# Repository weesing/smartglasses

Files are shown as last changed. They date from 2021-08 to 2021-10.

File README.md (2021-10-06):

# Overview
- This is a smart glasses prototyping project to use a MCU (Arduino/ESP32) or Raspberry Pi (SBC).
- **All resources here are WIP.**

# Folders
| Folder | Description
| -- | --
| STLs | Contains the STL files for 3D printing the parts of the smart glasses prototype.
| src | Contains source code for Arduino IDE based programming (suitable for Arduinos and ESP32) and Raspberry Pi.
| design | The design files used for producing the STLs. The current software used for design is Microsoft 3D Builder.

# Basic design
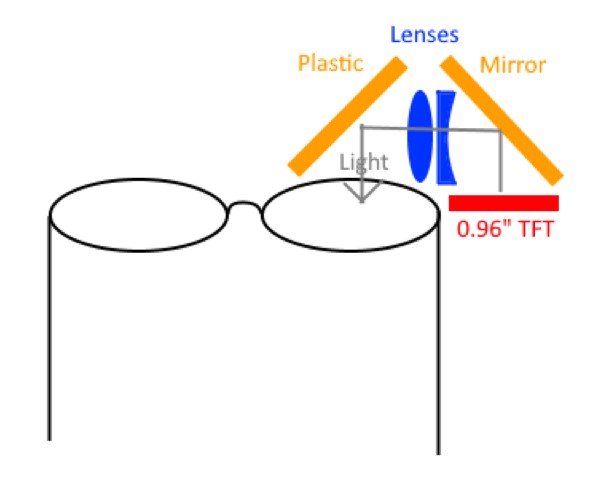
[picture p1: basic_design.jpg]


# Showcase
## Initial prototype with Arduino BLE Nano
<ul>
<li>Design with Arduino BLE Nano MCU and 0.49" OLED (monochrome) screen.
  <div class="row">
    <div class="col-md-12">
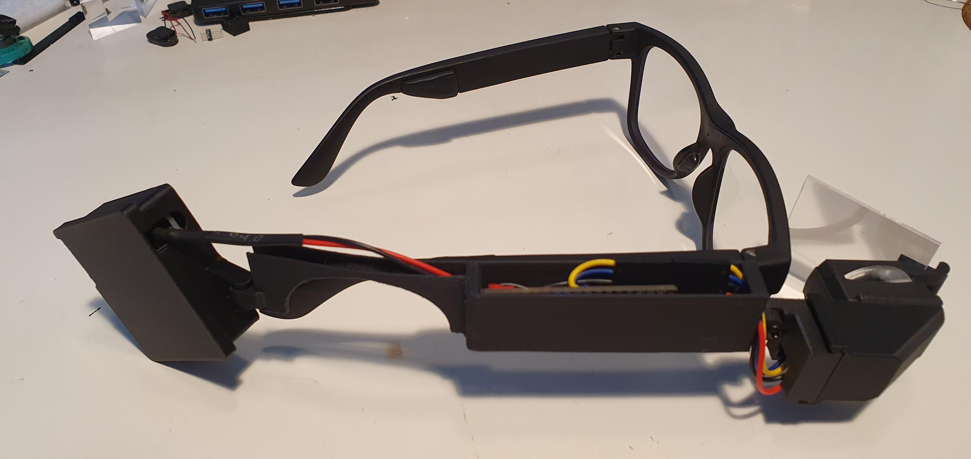
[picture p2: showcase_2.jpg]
    
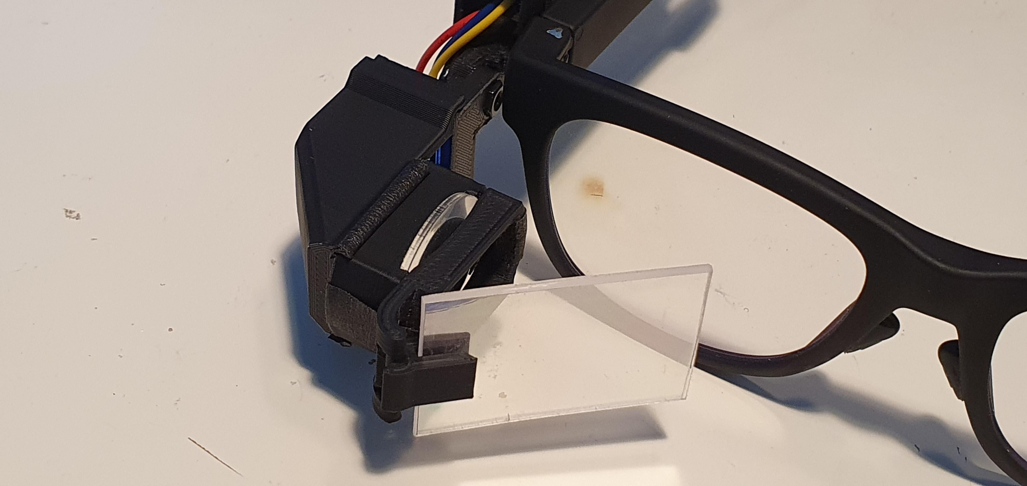
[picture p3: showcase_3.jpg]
    
    </div>
  </div>
</li>
<li>Code can be found in the sub-folder <code>src/arduino_ide</code></li>
</ul>

## Raspberry Pi Zero W console on the 0.96" TFT SPI display.
<ul>
<li>Displaying framebuffer of Raspbian Terminal on the display.</li>
  <div class="row">
    <div class="col-md-12">
    
    </div>
    <div class="col-md-12">
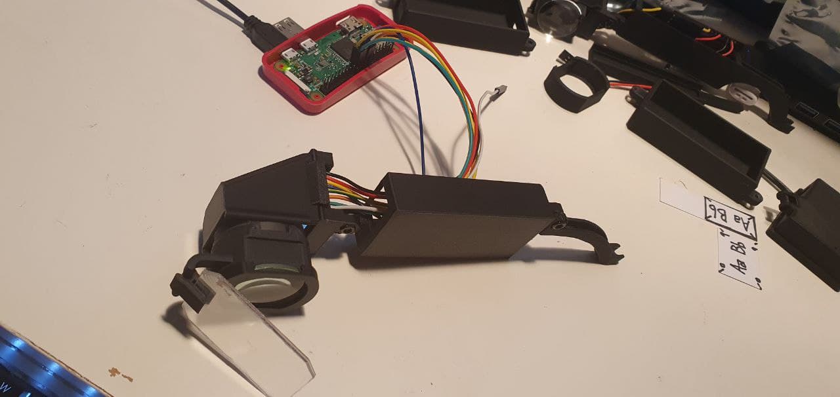
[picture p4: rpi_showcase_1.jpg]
    
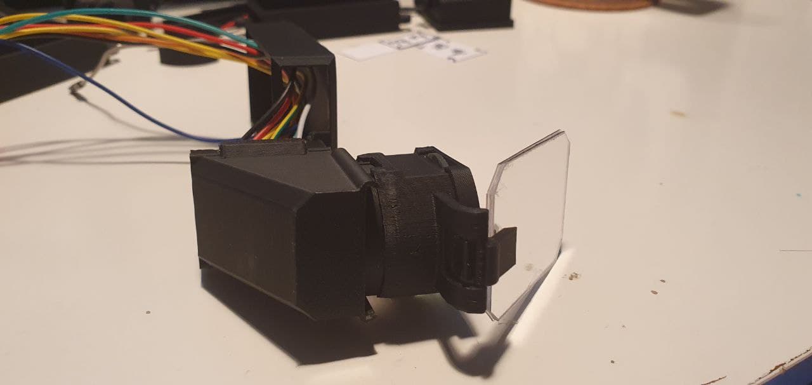
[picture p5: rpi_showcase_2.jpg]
    
    </div>
    <div class="col-md-12">
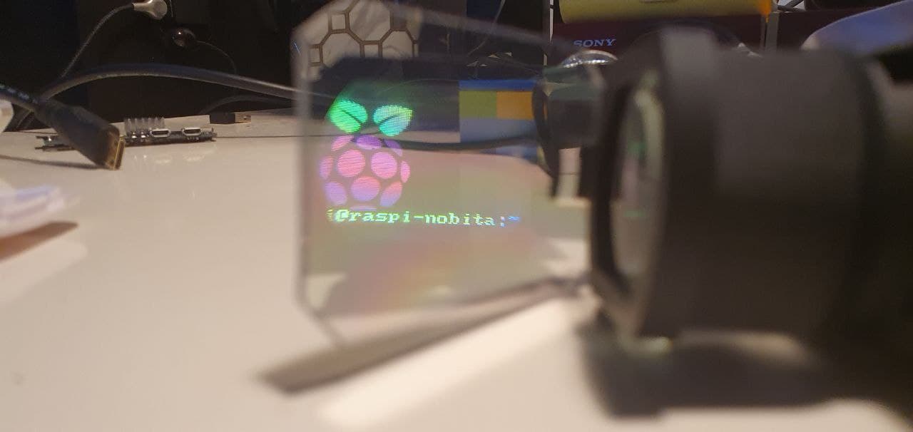
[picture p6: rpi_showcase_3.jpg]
    
    </div>
  </div>
<li>Code can be found in the folder <code>src/rpi</code></li>
</ul>

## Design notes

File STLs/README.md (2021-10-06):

# Overview
- This folder contains all the STL files used for 3D printing.
- The files are named 049*.stl, 0.96screenrgb*.stl for 2 different displays used in prototyping.

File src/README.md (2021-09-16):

# Smart Glasses Source Code

## Overview

- This folder contains the **source code** for the smart glasses project.
- Display used is the **ST7735S TFT display (0.96" 80x160)**.
- Look into the different sub-folders for the platform used. Currently evaluated platforms includes (but not limited to) **Arduino Nano BLE**, **ESP32 w Micropython** and **Raspberry Pi Zero W**.

## Sub-folders

| Folder | Description
| -- | --
| arduino_ide | Contains the sketch for using an Arduino BLE Nano MCU or ESP32 to connect to SPI ST7735S TFT (0.96" 80x160) display using the Arduino IDE
| micropython (to be deprecated) | Contains the Python code running MicroPython on the ESP32. This will be deprecated soon due to bad performance.
| rpi | Contains the software for mirroring Raspberry Pi framebuffer to the ST7735S TFT display.

# Findings Arduino BLE Nano/ESP32
- Arduino containing the compiled software updates the screen faster.
- ESP32 with Micropython is easier to develop due to the nature of scripting language (Python). BLE is also easier to configure and program (Arduino BLE programming requires more manual steps).
- Despite the ease of programming, MicroPython is bad in terms of performance due to the **interpreted** nature of the platform.
- Arduino BLE reception is limited to 20 bytes per packet (unable to configure so far), whereas ESP32 BLE allows configuration of the length of the packet size.
- Parsing of JSON (communication data format) is easier in Micropython/Python with readily built libraries. Since JSON is more verbose, ESP32's configurable data packet size (_see above_) has an advantage.
- ESP32 has wireless which opens other possibilities for integration with other devices for more info display on the smart glasses.
- Physical dimensions of ESP32 is twice of Arduino BLE Nano in terms of width, which will make the final design a little bit more bulky.
- BLE setup for ESP32 seems to be much easier than Arduino BLE Nano.
- Arduino IDE programming for ESP32 seems to be a best candidate after considering the above.

# Findings for Raspberry Pi Zero W
- Display is very tiny for displaying even the console (still barely usable though).
- There are more possibilities (such as running a full blown API server) on a Raspberry Pi.
- The physical footprint between ESP32 and RPi Zero W is quite similar, but given the extensibility of a full-blown computer, the RPi Zero W option seems to be much better.

# TODO

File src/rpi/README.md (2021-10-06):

# Overview
This project contains software that mirrors your Raspberry Pi's framebuffer (where a virtual screen resides) to an ST7735S 0.96" screen (80x160 resolution).

The software is part of the effort for display the Raspberry Pi's framebuffer for the smart glasses.

Source code originated & modified from the following repositories:
- https://github.com/vinodstanur/raspberry-pi-frame-buffer-mapping-to-160x128-ST7735R-LCD
- https://github.com/bersch/ST7735S 

# Pins Assignment
*Note: We are using SPI0 channel.*
| ST7355S | Raspberry Pi Zero W
| -- | --
| VCC | 3.3v
| GND | GND
| SCL | SLCK (GPIO 11)
| SDA | MOSI (GPIO 10)
| CS | GPIO 8 (can be configured in st7735.h)
| RST | GPIO 25 (can be configured in st7735.h)
| DC | GPIO 24 (can be configured in st7735.h)

# Before you run
- If you have freshly setup your Pi, you may be booting into the GUI desktop.
- The GUI desktop is not suitable for display on such a small screen. Therefore, it would be better to start your Pi into console instead 
> Note: You can configure your Pi to start in console/terminal mode through `raspi-config` or simply the `Preferences` menu in the GUI desktop).
- Enable SPI interface from `raspi-config` or `Preferences` menu in the GUI desktop.

# How to run
- Connect the ST7735S to your Raspberry Pi as described above.
- Change the framebuffer in `/boot/config.txt` to force the framebuffer width and height to 160 x 80 (you will need root access).
```
... (other settings)
framebuffer_width=160
framebuffer_height=80
... (other settings)
```
- Change to the project folder.
- Run `make`
- Run `./run.sh`

## Auto-run script when startup
- There is a systemd service in the project folder named `st7735s.service.sample`.
- Make a copy of this file into `st7735s.service`.
- Open the file and edit the field `WorkingDirectory` to where this project folder is (where `run.sh` script resides) if necessary.
- Make sure you have root access, and copy `st7735s.service` to the folder `/etc/systemd/system`.
- Run the commands:
```
sudo systemctl enable st7735s
sudo systemctl start st7735s
```
- Verify whether the console is shown on the TFT screen.
- To test whether the script runs across reboots, type:
```
sudo reboot now
```

# Screenshots
<div class="col-md-6">
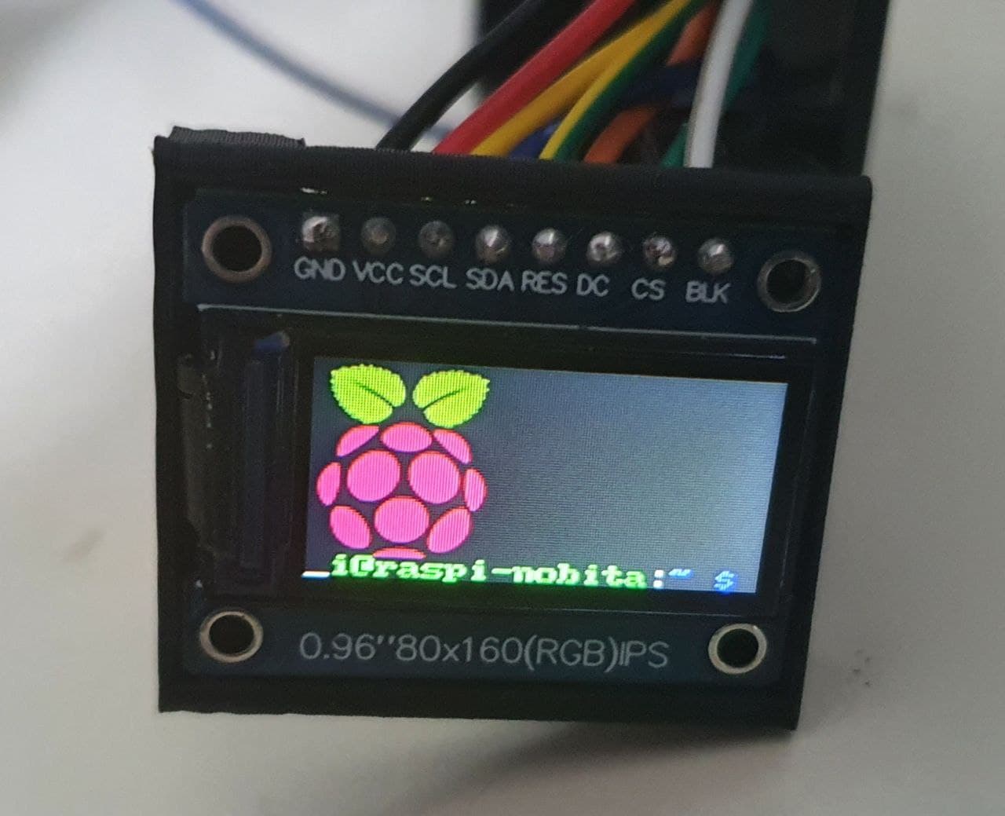
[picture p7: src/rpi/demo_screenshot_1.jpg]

</div>
<div class="col-md-6">
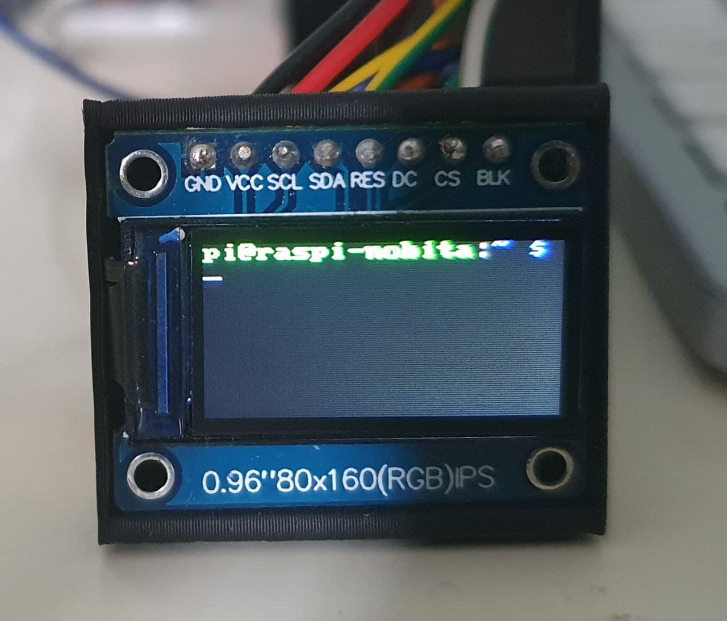
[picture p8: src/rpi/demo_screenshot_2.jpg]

</div>
<div class="col-md-12">
This is the terminal in action!
</div>
<div class="col-md-12">
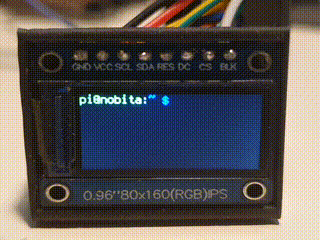
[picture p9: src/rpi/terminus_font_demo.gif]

</div>
<div class="col-md-12">
This is a demo running the GUI desktop (Spoiler: Unusable!)
</div>
<div class="col-md-12">

</div>

# References
- Guide - https://learn.adafruit.com/1-8-tft-display/python-wiring-and-setup

# Improvements
- To use pixel interpolation to translate higher resolution framebuffer to 160x80 resolution.

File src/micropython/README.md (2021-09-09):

# Micropython

| ST7735S | ESP32
| -- | --
| VCC | 3v3
| Gnd | Gnd
| SCK | Pin 14 (Default SPI)
| SDA | Pin 13 (Default SPI)
| DC | Pin 2
| RST | Pin 4
| CS | Pin 15
| BLK | None

* The source file `st7735s.py` is the **ST7735S** driver source.
* Ported from https://github.com/cheungbx/st7735-esp8266-micropython to support a new `BLUETAB80x160` configuration that displays with the orientation where the Pins on the board is at the *top*.

## Source
| File | Description
|--|--
| `boot.py` | Bootstrap code. Connection to Wifi. See `wifi_cfg.sample.py`
| `wifi_cfg.sample.py` | A sample source file containing Wifi configuration. Should rename this to `wifi_cfg.py`
| `main.py` | The main entry point.
| `sysfont.py` | Font file for displaying text on screen (credits: https://github.com/GuyCarver/MicroPython/tree/master/esp8266)
| `st7735s.py` | ST7735S display driver. Adapted from repository https://github.com/cheungbx/st7735-esp8266-micropython

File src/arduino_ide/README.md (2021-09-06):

# Arduino Nano BLE Software

## Pin Assignment
| ST7735S | Arduino Nano BLE | ESP32 NodeMCU
| -- | -- | --
| VCC | 5v | 3v3
| GND | GND | GND
| SDA | 11 | 23
| SCK | 13 | 18
| RST | 8 | 4
| DC | 9 | 2
| CS | 10 | 15
| BLK | 3v3 | None

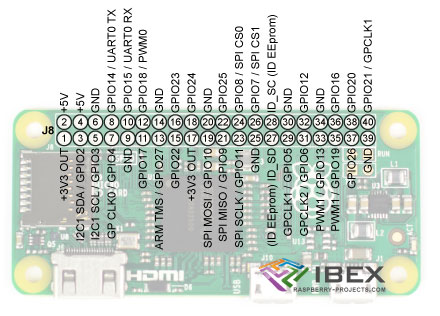
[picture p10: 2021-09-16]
src/rpi/rpi_zero_io_pinouts.jpg

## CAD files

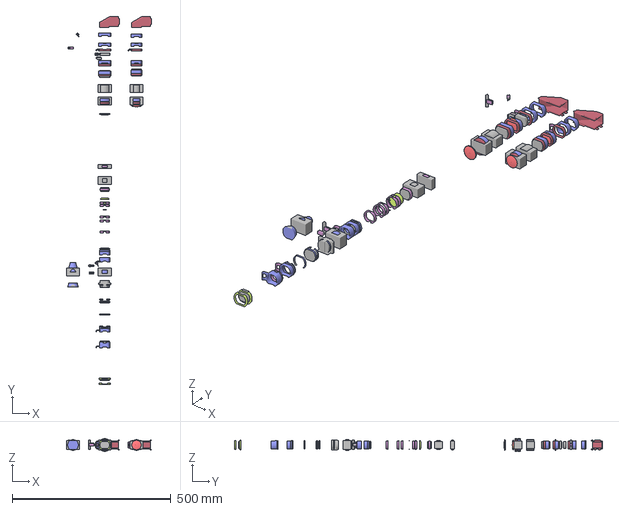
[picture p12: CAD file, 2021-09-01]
design/096screenrgb_lens.3mf
268.8 x 1159.1 x 40.0 mm

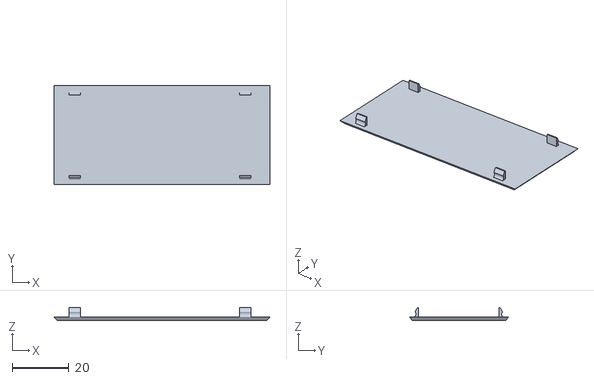
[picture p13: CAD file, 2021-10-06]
STLs/096screenrgb_stem_cover.stl
76.0 x 35.0 x 4.54

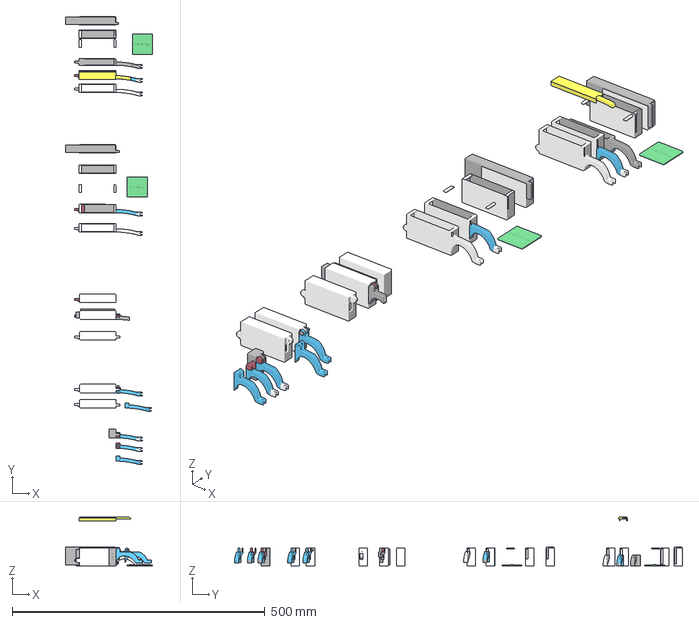
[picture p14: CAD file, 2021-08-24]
design/096screenrgb_stem.3mf
172.2 x 886.9 x 96.3 mm

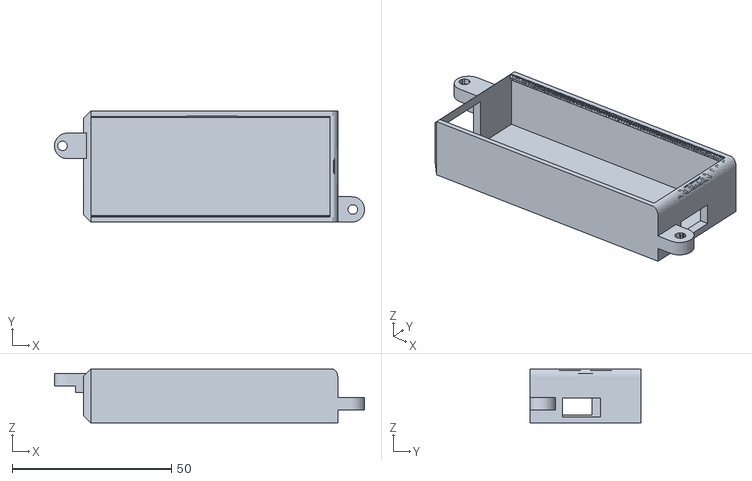
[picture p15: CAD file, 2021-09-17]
STLs/096screenrgb_stem.stl
97.5 x 35.0 x 17.0

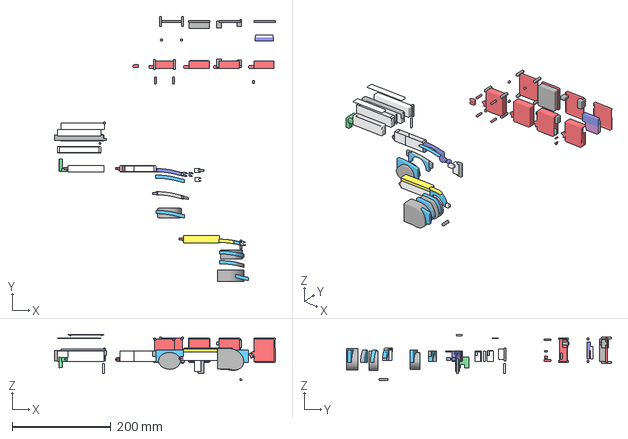
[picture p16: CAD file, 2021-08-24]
design/stem_battery.3mf
447.3 x 535.5 x 93.6 mm

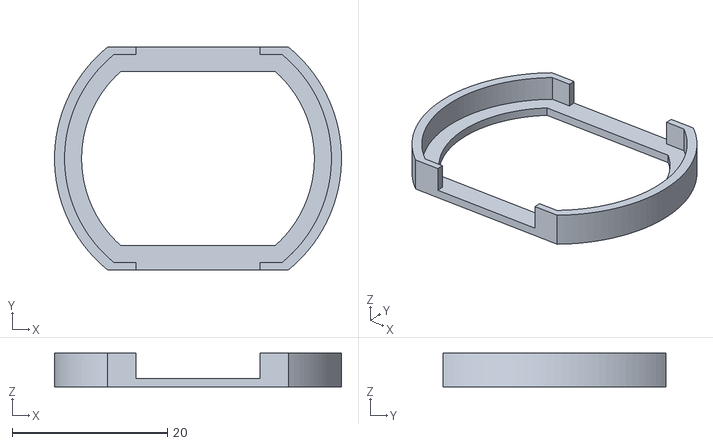
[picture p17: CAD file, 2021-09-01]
STLs/096screenrgb_lens_a_cover.stl
37.0 x 28.7 x 4.35

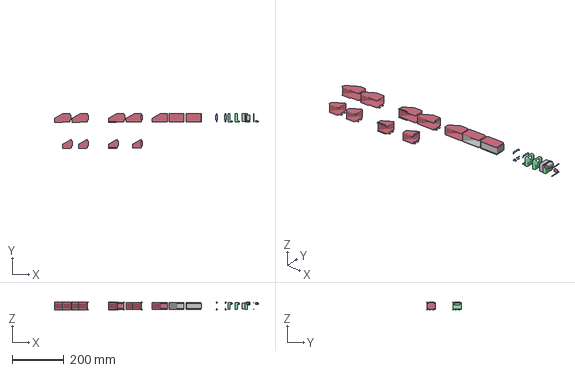
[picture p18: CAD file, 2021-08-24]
design/096screenrgb.3mf
785.2 x 134.7 x 31.3 mm

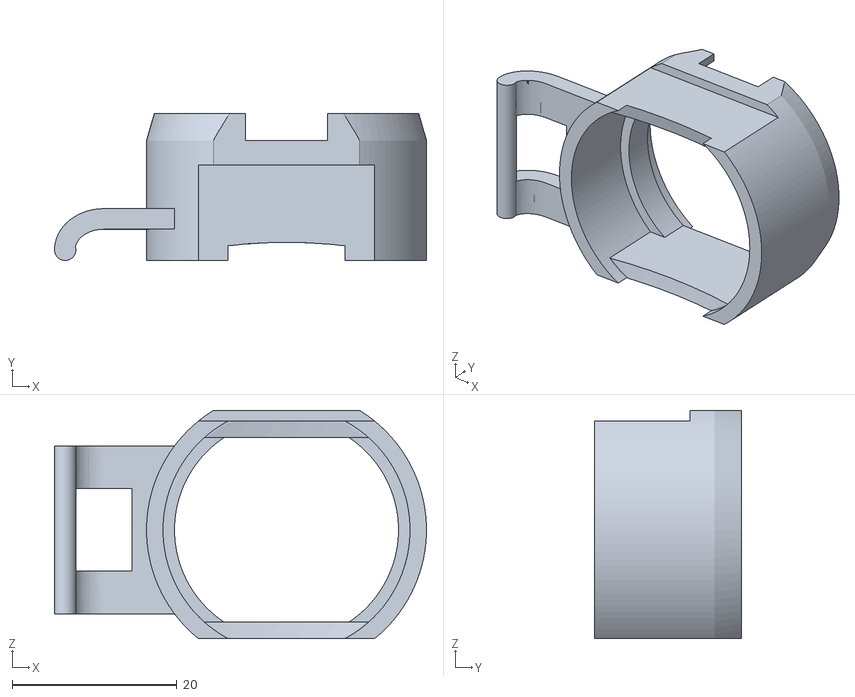
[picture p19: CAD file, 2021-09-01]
STLs/096screenrgb_lens_a.stl
45.2 x 17.8 x 27.7

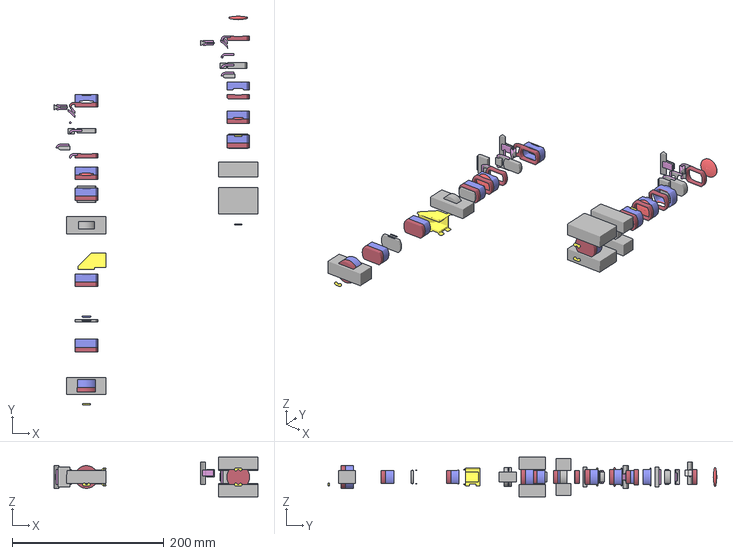
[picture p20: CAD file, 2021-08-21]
design/049lens.3mf
268.8 x 512.1 x 52.4 mm

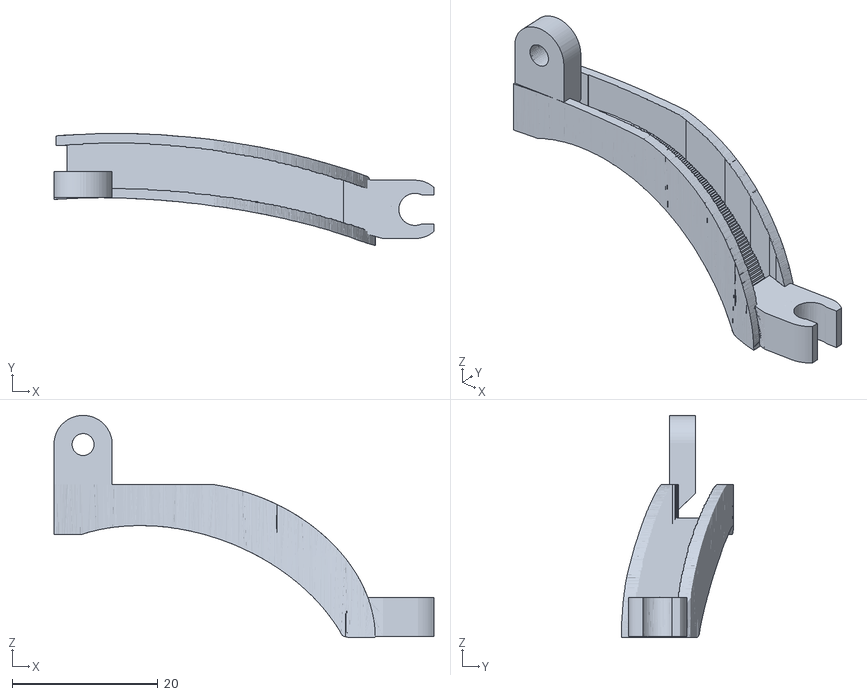
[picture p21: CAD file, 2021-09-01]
STLs/096screenrgb_stem_ear.stl
52.1 x 15.3 x 30.5

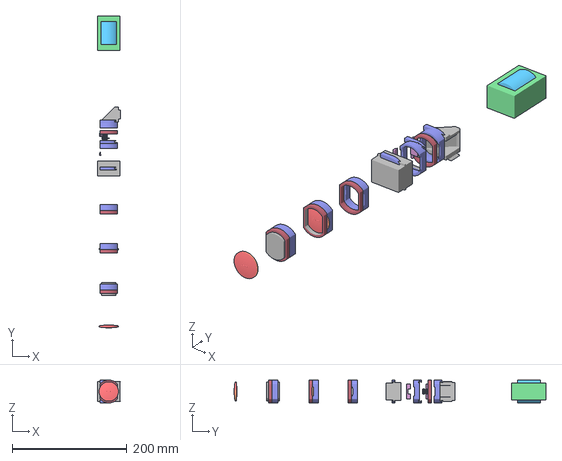
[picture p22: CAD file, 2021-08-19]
design/096lens.3mf
40.8 x 544.6 x 40.0 mm

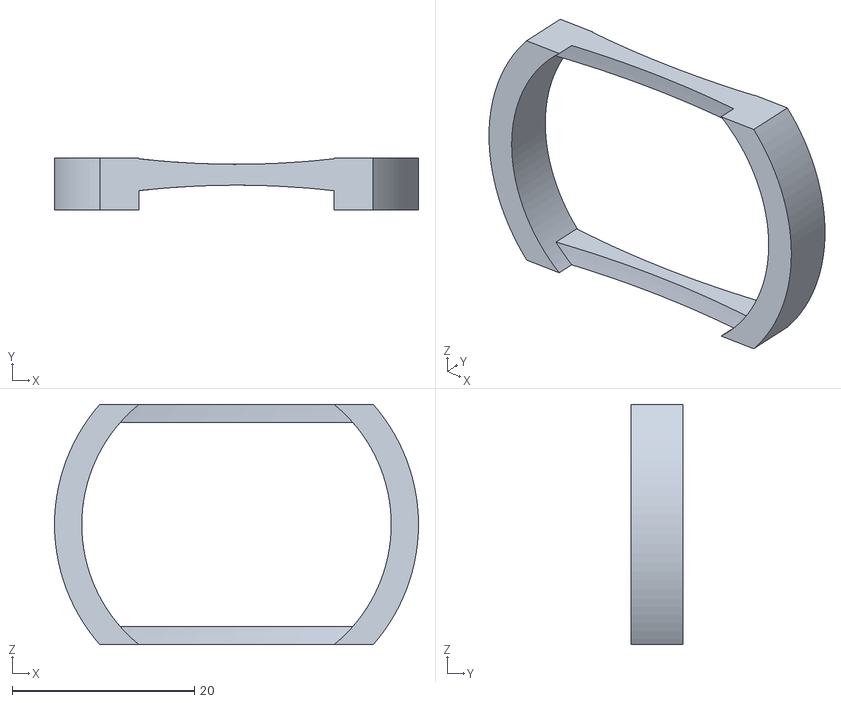
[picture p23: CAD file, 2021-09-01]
STLs/096screenrgb_lens_c.stl
40.0 x 5.70 x 26.4

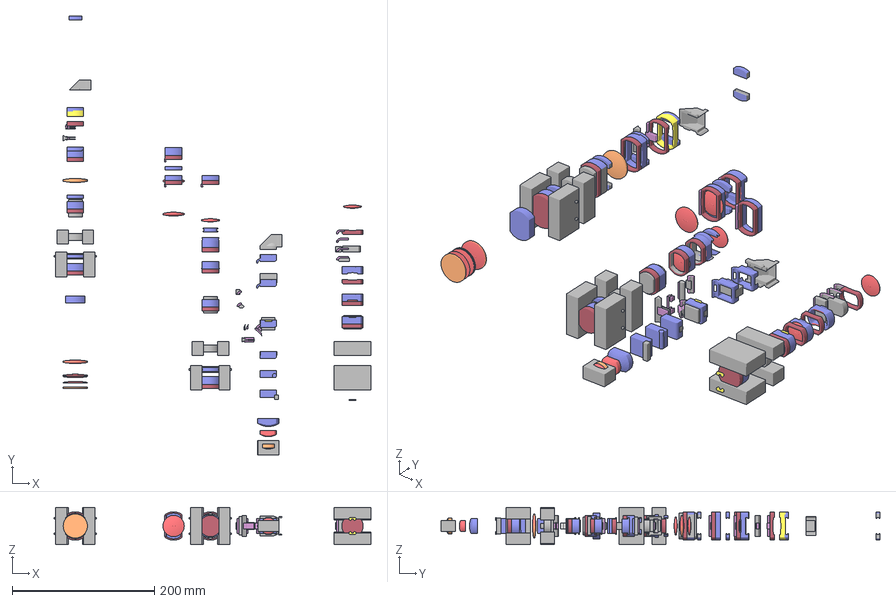
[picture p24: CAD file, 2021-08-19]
design/042lens.3mf
446.2 x 617.5 x 52.4 mm

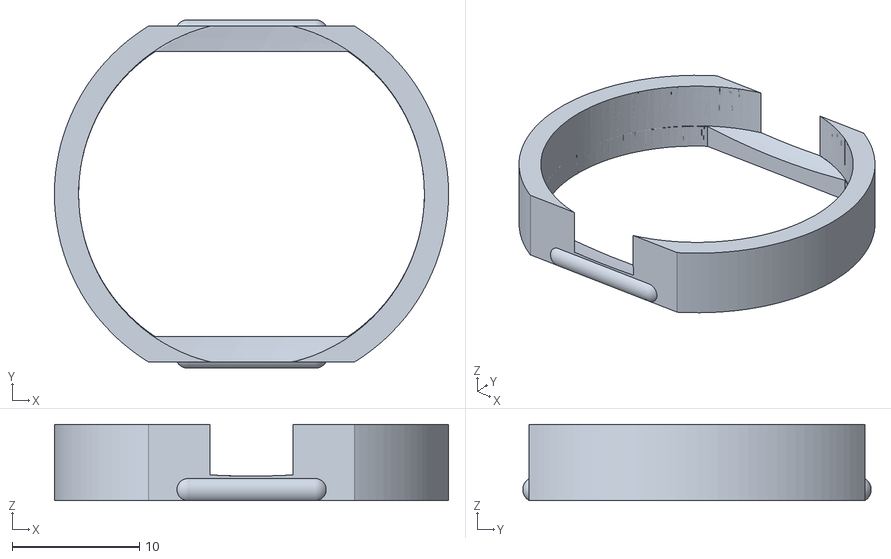
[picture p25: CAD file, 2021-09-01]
STLs/096screenrgb_lens_concave.stl
31.0 x 27.4 x 5.99

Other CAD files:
design/049screen.3mf
STLs/096screenrgb_housing.stl
design/042screen.3mf
STLs/stem.stl
STLs/049lens_a.stl
STLs/049lens_b.stl
STLs/049lens_display_arm.stl
STLs/049mirror_housing.stl
STLs/049screen_housing.stl
STLs/096screenrgb_lens_b.stl
STLs/096screenrgb_mirror_housing.stl
STLs/battery.stl
STLs/stem_cover.stl
design/096screen.3mf

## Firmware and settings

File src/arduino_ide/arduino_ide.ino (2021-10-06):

#include <Adafruit_GFX.h>    // Core graphics library
#include <Adafruit_ST7735.h> // Hardware-specific library for ST7735
#include <Adafruit_ST7789.h> // Hardware-specific library for ST7789
#include <SPI.h>
#include <ArduinoJson.h>

// Uncomment the following for ESP32
#define ESP32

#ifdef ESP32
#define TFT_CS 15
#define TFT_RST 4
#define TFT_DC 2
#include <BLEDevice.h>
#include <BLEUtils.h>
#include <BLEServer.h>
#define SERVICE_UUID "4fafc201-1fb5-459e-8fcc-c5c9c331914b"
#define CHARACTERISTIC_UUID "beb5483e-36e1-4688-b7f5-ea07361b26a8"
BLECharacteristic *gp_Characteristics = NULL;
#else
// For the breakout board, you can use any 2 or 3 pins.
// These pins will also work for the 1.8" TFT shield.
#define TFT_CS 10
#define TFT_RST 8 // Or set to -1 and connect to Arduino RESET pin
#define TFT_DC 9
#endif

// #define TEST_DISPLAY

Adafruit_ST7735 tft = Adafruit_ST7735(TFT_CS, TFT_DC, TFT_RST);

#define MSG_TYPE_TEXT 1

void displaySetup()
{
  tft.initR(INITR_MINI160x80); // Init ST7735S mini display
  tft.setRotation(1);
  tft.invertDisplay(true);
  tft.fillScreen(ST7735_BLACK);
  // tft.setSPISpeed(100000000);
}

#ifdef ESP32
class CharacteristicCallbacks : public BLECharacteristicCallbacks
{
  void onRead(BLECharacteristic *pCharacteristic) {}

  void onWrite(BLECharacteristic *pCharacteristic)
  {
    Serial.println("On Write");
    String buffer = String(pCharacteristic->getValue().c_str());

    Serial.println(buffer);
    // TODO: Process buffer from JSON string in buffer
    pCharacteristic->setValue("");

    StaticJsonDocument<200> doc;
    // Deserialize the JSON document
    DeserializationError error = deserializeJson(doc, buffer);

    // Test if parsing succeeds.
    if (error)
    {
      displayMessage(F("System"), F("deserializeJson() failed"));
      Serial.println(error.f_str());
    }
    else
    {
      uint32_t type = doc["type"];
      String title = doc["title"];
      String content = doc["content"];
      if (type != NULL)
      {
        switch (type)
        {
        case MSG_TYPE_TEXT:
          displayMessage(title, content);
          break;
        default:
          displayMessage(F("System"), F("Unknown message type encountered. Aborting display."));
          break;
        }
      }
      else
      {
        Serial.println(F("Unknown message type. Aborting parsing."));
      }
    }

    delay(200);
  }

  void onNotify(BLECharacteristic *pCharacteristic)
  {
    Serial.println("On Notify");
  }

  void onStatus(BLECharacteristic *pCharacteristic, Status s, uint32_t code) {}
};
#endif // #ifdef ESP32

void displayMessage(const String title, const String content)
{
  Serial.println(title);
  Serial.println(content);
  tft.fillScreen(ST7735_BLACK);
  tft.setCursor(0, 0);
  tft.setTextColor(ST7735_YELLOW);
  tft.setTextWrap(true);
  tft.print(title.c_str());
  tft.setCursor(0, 20);
  tft.setTextColor(ST7735_WHITE);
  tft.print(content.c_str());
}

void bleSetup()
{
#ifdef ESP32
  Serial.println("Starting BLE work!");

  BLEDevice::init("ESP32 Smart Glasses");
  // Create server
  BLEServer *pServer = BLEDevice::createServer();
  // Create service
  BLEService *pService = pServer->createService(SERVICE_UUID);
  // Create characteristic
  gp_Characteristics = pService->createCharacteristic(
      CHARACTERISTIC_UUID,
      BLECharacteristic::PROPERTY_READ | BLECharacteristic::PROPERTY_WRITE | BLECharacteristic::PROPERTY_NOTIFY);

  // Set initial value and start service
  gp_Characteristics->setValue("");

  // Set the callbacks to the characteristics
  CharacteristicCallbacks *pCallbacks = new CharacteristicCallbacks();
  gp_Characteristics->setCallbacks(pCallbacks);

  pService->start();

  // Advertising service
  BLEAdvertising *pAdvertising = BLEDevice::getAdvertising();
  pAdvertising->addServiceUUID(SERVICE_UUID);
  pAdvertising->setScanResponse(true);
  pAdvertising->setMinPreferred(0x06);
  BLEDevice::startAdvertising();

  Serial.println("Characteristic defined! Now you can read it in your phone!");
#endif // #ifdef ESP32
}

void setup(void)
{
  Serial.begin(115200);

  displaySetup();
  bleSetup();

  uint16_t time = millis();
  time = millis() - time;
}

#ifdef TEST_DISPLAY
void testPrintText()
{
  uint16_t colors[] = {ST7735_WHITE, ST7735_YELLOW, ST7735_GREEN, ST7735_RED, ST7735_BLUE};
  for (uint8_t i = 0; i < sizeof(colors) / sizeof(colors[0]); ++i)
  {
    // large block of text
    tft.fillScreen(ST77XX_BLACK);
    tft.setCursor(0, 0);
    tft.setTextColor(colors[i]);
    tft.setTextWrap(true);
    tft.print("Lorem ipsum dolor sit amet, consectetur adipiscing elit. Curabitur adipiscing ante sed nibh tincidunt feugiat. Maecenas enim massa, fringilla sed malesuada et, malesuada sit amet turpis. Sed porttitor neque ut ante pretium vitae malesuada nunc bibendum. Nullam aliquet ultrices massa eu hendrerit. Ut sed nisi lorem. In vestibulum purus a tortor imperdiet posuere.");
    delay(1000);
  }
}

#define R_SIZE 5
#define G_SIZE 6
#define B_SIZE 5
const uint8_t R_MAX = pow(2, R_SIZE);
const uint8_t G_MAX = pow(2, G_SIZE);
const uint8_t B_MAX = pow(2, B_SIZE);
#define TILE_WIDTH 16
#define TILE_HEIGHT 16
#define TILE_DISPLAY_TIMES 30

void testPrintTiles()
{
  for (uint8_t times = 0; times < TILE_DISPLAY_TIMES; ++times)
  {
    for (uint8_t y = 0; y < 80; y += TILE_HEIGHT)
    {
      for (uint8_t x = 0; x < 160; x += TILE_WIDTH)
      {
        uint8_t r = rand() % R_MAX;
        uint8_t g = rand() % G_MAX;
        uint8_t b = rand() % B_MAX;
        uint16_t color = (r << G_SIZE + B_SIZE) | (g << B_SIZE) | b;
        tft.fillRect(x, y, TILE_WIDTH, TILE_HEIGHT, color);
      }
    }
    delay(50);
  }
  delay(2000);
}
#endif // #ifdef TEST_DISPLAY

void displayLoop()
{
#ifdef TEST_DISPLAY
  testPrintText();
  testPrintTiles();
#endif // #ifdef TEST_DISPLAY
}

void loop()
{
  displayLoop();
}

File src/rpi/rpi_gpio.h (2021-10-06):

#define GPIO_BASE 0x3f200000UL
//#define GPIO_BASE       0x20200000UL
//#define GPIO_BASE       0xf2200000UL

#define GPIO_GPFSEL0 0
#define GPIO_GPFSEL1 1
#define GPIO_GPFSEL2 2
#define GPIO_GPFSEL3 3
#define GPIO_GPFSEL4 4
#define GPIO_GPFSEL5 5

#define GPIO_GPSET0 7
#define GPIO_GPSET1 8

#define GPIO_GPCLR0 10
#define GPIO_GPCLR1 11

#define GPIO_GPLEV0 13
#define GPIO_GPLEV1 14

#define GPIO_GPEDS0 16
#define GPIO_GPEDS1 17

#define GPIO_GPREN0 19
#define GPIO_GPREN1 20

#define GPIO_GPFEN0 22
#define GPIO_GPFEN1 23

#define GPIO_GPHEN0 25
#define GPIO_GPHEN1 26

#define GPIO_GPLEN0 28
#define GPIO_GPLEN1 29

#define GPIO_GPAREN0 31
#define GPIO_GPAREN1 32

#define GPIO_GPAFEN0 34
#define GPIO_GPAFEN1 35

#define GPIO_GPPUD 37
#define GPIO_GPPUDCLK0 38
#define GPIO_GPPUDCLK1 39

void gpio_mode_output(unsigned int pin);
void gpio_set_pin(unsigned int pin);
void gpio_clear_pin(unsigned int pin);
void gpio_init(void);

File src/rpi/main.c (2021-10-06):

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
You should have received a copy of the GNU General Public License
along with this program.  If not, see <http://www.gnu.org/licenses/>*/
///////////////////////////////////////////////////////////////////////
#include <stdio.h>
#include <sys/time.h>
#include <string.h>
#include <fcntl.h>
#include <linux/fb.h>
#include <sys/mman.h>
#include <sys/ioctl.h>
#include <inttypes.h>
#include <stdlib.h>
#include "st7735s.h"
#include <sys/stat.h>
#include <sys/types.h>
#include <unistd.h>
#include <arpa/inet.h>
#include "rpi_spi.h"
#include "rpi_gpio.h"
#include "st7735s_compat.h"
#include <endian.h>

//#define debug
//#define TEST_FILL
#define SCR_WIDTH 160
#define SCR_HEIGHT 80

//uint16_t fb2[128 * 160];
uint16_t fb2[SCR_HEIGHT * SCR_WIDTH];
uint8_t g_screenOffset[] = {0, 24};

void testScreenFill(void)
{
  uint16_t *p;
  while (1)
  {
    p = fb2;
    struct timeval now;
    gettimeofday(&now, NULL);
    srand(now.tv_usec);
    // srand(time(NULL));
    uint8_t r = rand() % 0xff;
    uint8_t g = rand() % 0xff;
    uint8_t b = rand() % 0xff;
    uint16_t initColor = RGB565(r, g, b);
    // uint16_t initColor = RGB565(0x0, 0x0, 0xff);
#ifdef debug
    printf("Initializing color to 0x%x, address=0x%x\n", initColor, p);
#endif
    for (uint32_t i = 0; i < SCR_WIDTH * SCR_HEIGHT; ++i)
    {
      *p++ = initColor;
    }
#ifdef debug
    printf("Color initialized, address=0x%x\n", p);
#endif
    p = fb2;

    Pin_CS_Low();

    ST7735S_addrset(
        g_screenOffset[0],
        g_screenOffset[1],
        g_screenOffset[0] + SCR_WIDTH - 1,
        g_screenOffset[1] + SCR_HEIGHT - 1);

    Pin_DC_High();
#ifdef debug
    printf("Copying framebuffer...\n");
#endif

    uint32_t stride = SCR_WIDTH;
    for (uint32_t i = 0; i < SCR_HEIGHT; i++)
    {
      spi_write_16(0, p, stride);
      p += stride;
    }

#ifdef debug
    printf("Screen copied\n\n\n");
#endif

    // Uncomment this to have interval between color fills.
    usleep(300000);
  }
}

int main()
{
  int fbfd = 0;

  struct fb_var_screeninfo vinfo;
  long int screensize = 0;
  uint8_t *fbp = 0;
  int i;
  uint16_t *p = fb2;
  int xx = 0;
  int yy = 0;

  Delay(2000);

  fbfd = open("/dev/fb0", O_RDWR);

  ST7735S_Init();

  memset(fb2, 0, sizeof(fb2));
  printf("fb2 size = %d bytes\n", sizeof(fb2));

#ifdef TEST_FILL
  testScreenFill();
#endif // #ifdef TEST_FILL

  while (1)
  {
    usleep(50000);

    ioctl(fbfd, FBIOGET_VSCREENINFO, &vinfo);
#ifdef debug
    printf("X = %d, Y = %d, bits per pixel = %d\n", vinfo.xres, vinfo.yres, vinfo.bits_per_pixel);
#endif
    Pin_CS_Low();

    ST7735S_addrset(
        g_screenOffset[0],
        g_screenOffset[1],
        g_screenOffset[0] + SCR_WIDTH - 1,
        g_screenOffset[1] + SCR_HEIGHT - 1);

    Pin_DC_High();

    screensize = vinfo.xres * vinfo.yres * vinfo.bits_per_pixel / 8;
#ifdef debug
    printf("screensize = %d bytes (X * Y * 32 / 8)\n", screensize);
#endif
    // const int PADDING = 4096;
    int mmapsize = screensize;
#ifdef debug
    printf("mapsize = %d\n", mmapsize);
#endif
    fbp = (char *)mmap(0, mmapsize, PROT_READ | PROT_WRITE, MAP_SHARED, fbfd, 0);

    p = fb2;
    // 32 bits to 16 bits
    uint8_t *pPixel = (uint8_t *)fbp;
    for (uint16_t row = 0; row < SCR_HEIGHT; ++row)
    {
      uint16_t *rowStart = p;
      for (uint16_t col = 0; col < SCR_WIDTH; ++col)
      {
        uint8_t b = *pPixel;
        ++pPixel;
        uint8_t g = *pPixel;
        ++pPixel;
        uint8_t r = *pPixel;
        pPixel += 2; // + alpha
        *p = RGB565(r, g, b);
        ++p;
      }
    }

    munmap(fbp, screensize);

    p = fb2;
    uint32_t stride = SCR_WIDTH;
    for (uint32_t i = 0; i < SCR_HEIGHT; i++)
    {
      spi_write_16(0, p, stride);
      p += stride;
    }
  }

  Pin_CS_High();
  printf("done\n");

  close(fbfd);

  return 0;
}

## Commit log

2021-08-19 Design and models
    [042lens.3mf, 042screen.3mf, 049lens.3mf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]
2021-08-19 Created printable STLs
    [049lens.3mf, 049lens_a.stl, 049lens_b.stl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]
2021-08-19 Updated stem to better fit glass ear curve
    [stem.stl]
2021-08-19 Commit changes to stem design
    [stem_battery.3mf]
2021-08-21 0.96in TFT design and STLs
    [049lens.3mf, 096screenrgb.3mf, 096screenrgb_housing.stl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]
2021-08-21 Change Z seam for lens B
2021-08-24 Tweak screen housing to have more wire out space. Tweak stem to have more space.
    [096screenrgb.3mf, 096screenrgb_housing.stl, 096screenrgb_lens.3mf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]
2021-08-31 ESP32 init
2021-09-01 RGB screen st7735s
    [096screenrgb_lens.3mf, 096screenrgb_lens_a.stl, 096screenrgb_lens_a_cover.stl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]
2021-09-01 ST7735S driver and test font
2021-09-01 Remove MADCTL debug print. Changing test text display sentence.
2021-09-04 Added sample BMP for ESP32. Added arduino test display code
2021-09-06 Update Arduino for ESP32
2021-09-06 Change arduino code name.
2021-09-09 Renamed 'esp32' folder to 'micropython'.
2021-09-10 Initializing BLE on ESP32
2021-09-10 Reading and printing value from BLE characteristics.
2021-09-11 Removing loop since we have callbacks, it won't be necessary.
    [arduino_ide.ino]
2021-09-11 Avoiding unknown message type.
    [arduino_ide.ino]
2021-09-11 Print error using display.
    [arduino_ide.ino]
2021-09-16 Rename service file to sample. Edited readme.
2021-09-16 Added SPI interface enable.
2021-09-16 Updated README for TODO and notes for BLE setup for ESP32.
2021-09-16 Comments for ESP32 predicate.
2021-09-16 Added a README in main folder and STL folder.
2021-09-16 Fixed wrong voltage in RPI README
2021-09-17 Remove interpolation, doesn't work
    [main.c]
2021-09-17 Longer stem to fit RPi.
    [096screenrgb_stem.stl]
2021-09-20 reverting to before cmd/data.
    [st7735s.c]
2021-10-06 Stem cover
    [096screenrgb_stem_cover.stl]

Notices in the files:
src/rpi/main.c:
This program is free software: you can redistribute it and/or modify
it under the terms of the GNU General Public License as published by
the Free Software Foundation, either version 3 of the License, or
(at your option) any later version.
